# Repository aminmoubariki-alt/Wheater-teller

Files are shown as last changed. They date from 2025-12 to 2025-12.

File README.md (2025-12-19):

# IoT moubara

Repository of Amin Moubariki (500860959)
This is my first commit!
het gaat nu goed met git

## Week 1

Dinsdag 6 september.
Vandaag ben ik begonnen met de Git workshop, helaas heb ik deze niet helemaal afgemaakt, omdat ik ook nog mijn wemos ging solderen.
Morgen ga ik verder met het laten werken van Git, Het solderen is goed gelukt en het installeren van de arduino software ook.

Woensdag 7 september.
Vandag heb ik de tutorial afgemaakt en mijn Git pagina werkend gekregen. De eerst commits staan er succesvol om als ik naar mijn pagina ga op gitlab.

Doenderdag 8 September.
Tijdens de les van Joey heb ik al een beetje kunnen oefenen met 3D printing, Ik heb ervoor gekozen om een sleteulhanger te printen.
Het downloaden en bewerken van het design is goed gelukt en ik heb al beter begrepen hoe ik de 3D printer kan gebruiken. 

## Week 2

Maandag 12 september.
Ik heb mijn tempratuursensor succesvol geinstaleerd, Het laten werken van ervan lukt nog niet echt.
Dat is voor deze week mijn uitdaging.

Woensdag 14 september.
Vandaag heb ik mijn documentatie ook daadwerkelijk gecommit zodat het op mijn pagina op gitlab komt te staan.
Verder heb ik aan mijn weather station blueprint gewerkt en een scherm toegevoegd aan het breadboard met behulp van een backpack.
Ik heb het scherm aan de backpack gesoldeerd zodat ik het scherm makkelijker kan verwerken later in mijn project.

## Week 3

Maandag 19 september.
Het is vandaag een wat mindere dag qua progressie. Mijn git geeft steeds aan fatal code en het is mij niet gelukt om er zelf uit te komen,
Deze code kwam steeds wanneer ik iets probeerde te committen. Ik ben er vandaag niet uitgekomen en ga deze week daarom om hulp vragen.

Woensdag 21 september.
Het doel van vandaag was mijn git op orde krijgen zodat ik elke dag kan committen en pushen naar mijn pagina op gitlab.
Het is gelukt, een medestudent heeft alles op orde gekregen en mijn map via github geconnect met mijn pagina. 
Nu kan ik weer pushen en committen en blijven documenteren terwijl de docenten dat ook kunnen zien.

## Week 4

Maandag 26 september.
Ik heb vandaag feedback gevraagd voor Physical design van mijn wheaterstation. Ik heb Foto's gemaakt van mijn embedded device en deze toegevoegd aan het markdown bestand.
Aan mijn embedded device is een tempratuursensor aan verbonden en een lcd scherm met de wemos. Mijn scherm is nog blauw en speelt nog niks af en daar ga ik deze week mee aan de slag.
Het doel voor deze week is dus vooral ervoor zorgen dat mijn display op zijn minst de tempratuur kan afspelen.

Dinsdag 27 september.
Vandaag heb ik geprobeerd om wat meer te leren over PHP en om tekste af te spelen op mijn LCD scherm. Ik heb een hele rare error gekregen namelijk dat er geen poort geselecteerd is.
Dit is gek want ik heb aan het begin van dit project de CH340 driver succesvol geinstalleerd. Ik moet nu eerst dit probleem oplossen voordat ik echt verder kan helaas.
De code om iets af te spelen op mijn scherm klopt, er zaten geen fouten in en het zou helemaal moeten kloppen.
Het probleem is nu vooral dat de arduino app en mijn pc mijn embedded device niet kan herkennen en daar moet ik nu achteraan.

Woensdag 27 september.
Het maken van de poort gaat nog niet helemaal als gepland. Ik heb alles geprobeerd en ik zie dat het mij deze week heel veel tijd heeft gekost en mij heeft afgeremd.
Ik heb daarom besloten om te kijken naar mijn website met docker en daar is het ook gelijk fout gegaan, omdat WSL mist. Dus ik moet nu weer wat anders gaan doen.
Deze knelpunten hoop ik deze week te hebben verholpen anders ga ik vertraging oplopen en de deadline van de blueprint fase niet halen.

## Week 5

Maandag 3 Oktober.
Vandaag heb ik geprobeerd om aan mijn project te werken maar doordat ik ziek was heb ik weinig kunnen toevoegen, ik ben daarom ook niet lang op de campus gebleven.
Vandaar dat er daarom weinig is aangevuld en mijn problemen (port vooral) nog niet zijn opgelost. Ik hoop dat ik morgen een flinke slag kan maken.

Dinsdag 4 Oktober.
Het is eindelijkt gelukt om mijn poort werkend te krijgen, ik had blijkaar allemaal oplaadkabels getest in plaats van data-kabels zonder dat ik dat wist.
er was ook al een hoop gedoe met mijn website wat vandaag ook verholpen is door de map te verplaatsten. Gelukkig werkt alles nu zoals het hoort en moet er nu een slag worden gemaakt met mijn code.
De arduino code krijg ik maar niet werkend en de tijd begint echt te dringen. Ik hoop daat ik morgen dan ook mijn arduino code grotendeels af en werkend kan hebben.
Ik wil verder ook nog ervoor zorgen er nog 1 input sensor en 1 output part wordt toegevoegd zodat ik dat ook met mijn code kan invoegen.

Woensdag 5 Oktober.
Het gaat de verkeerde kant op met mijn blueprint, zojuist heb ik erachter gekomen dat er kortsluiting is op mijn embedded device waar ik nu een maand mee bezig ben.
Alles heb ik van mijn breadbord uit moeten halen en nu ben ik helemaal opnieuw begonnen met in elkaar zetten. De code werkt ook niet zoals verwacht.
Mijn Wemos verbind goed met mijn pc alleen als ik wat wil afspelen op het display komt er niks tevoorschijn. De Wemos is goed verbonden met het display.
Dit is wel een zware tik voor mij net nu ik dacht dat ik het wel begreep, ik moet nu bijna als het ware weer bij nul beginnen met nog een week te gaan.

## Week 6

Maandag 10 Oktober.
Deze maandag ben ik weer niet lekker uit bed gestapt, ik probeer morgen met wat paracetamol naar school te komen.

Dinsdag 11 Oktober.
Vandaag ben ik erachter gekomen dat mijn lcd scherm totaal niet functioneert er gaat alleen stroom naar het scherm toe thats it.
Na wat research geedaan te hebben ben ik op het arduino forum tegengekomen dat het wellicht met het soldeerwerk te maken heeft.
Ik heb vervolgens het scherm opnieuw gesoldeerd (nieuw scherm dit keer) en na wat zoeken en sleutelen doet mijn scherm het weer volledig.
Dit heeft mij enorm weerhouden van mijn vooruitgang en ik ben hier veel telaat achter gekomen. Het kan niet zo langer doorgaan op deze manier werken.
Volgende stap is om de tempratuur sensor af te spelen op mijn LCD scherm.

Woensdag 12 Oktober.
Vandaag heb ik mijn tweede performance review gehouden met mijn coach Mats. Het gaat niet goed met mijn vooruitgang en er moet snel iets veranderen.
Ik loop zwaar achter aangezien de blueprint fase deze week al af had moeten zijn. Momenteel heb ik een tempratuursensor en een LCD scherm derin zitten.
De tempratuur sensor is werken en er moet alleen nog code worden toegevoegd om deze af te spelen op mijn LCD scherm.
Er moet verder nog gewerkt worden aan de web applicatie en de database daarvan. Mijn plan is om dit over twee weken af te hebben met feedback om de puntjes op de I te zetten.

Herfstrecess.
Tijdens dit recess heb ik een flinke slag moeten maken met het werkend maken van mijn blueprint. Dat is aardig gelukt het embedded gedeelte is nu bijna af en werkt volledig.
Zo heb ik een tempratuursensor toegevoegd en worden de waarden die worden gemeeten op mijn display afgespeeld. Het heeft even geduurd maar alles werkt nu op het eerste gezicht en moet nog breed getest worden.
Ik heb een website die nog leeg is en een zeer beperkte database waar allen de tempratuur op wordt opgeslagen. Na het testen wil ik nog een knop, humiditysensor en een twee leds toevoegen aan mijn device.
Zoals het er voor nu uitziet ben ik goed opweg en moet ik vooral aan mijn documentatie, web app en database gaan werken voor dit project.

Maandag 24 Oktober.
Vandaag het ik mijn wheaterstation met de API verbonden zodat er ook vannuit daar informatie kan worden opgehaald en natuurlijk worden afgespeeld op het lcd scherm.
Het plan voor nu is om ervoor te zorgen dat zowel de tempratuur van buiten, met behulp van de API, als de binnentempratuur op het beeldscherm wordt afgespeeld.
Dit ga ik morgen proberen uitbreiden naar humidity van binnen door een DHT11 sensor toe te voegen aan mijn device.
Voordat ik een sensor ga toevoegen moeten de juiste waardes met de huidige tempratuursensoor goed worden afgespeeld.

Dinsdag 25 Oktober.
Het is mij gelukt om de DHT11 sensor toe te voegen zodat ik de lokaale humidity kan afspelen met de tempratuur.
Ook ben ik er achtergekomen dat deze DHT11 sensor de tempratuur accurater meet en, daarom heb ik besloten om mijn KY001 niet meer te gebruiken.
Nu ga ik ervoor zorgen dat de binnen en buiten humidity en tempratuur correct worden afgespeeld op mijn LCD scherm met behulp van de sensoren en de API.

Woensdag 26 Oktober.
Uit de performance review dat ik vandaag heb gehouden met mijn coach is gebleken dat ik flink vooruit ben gegaan, maar dat eer nog genoeg te doen is.
Daarom ga ik ook zo snel moegelijk beginnen met het vragen voor feedback voor de embedded kant, omdat ik daar veel aan gewerkt heb.
De kant waar nog best wat aan gedaan moet worden is de web app en de database daarvan. Ik hoop deze uiterlijk voor de volgende performance review af te hebben.
Voor de volgende performance review hoop ik ook het grootste gedeelte van de feedback te hebben ontvangen.

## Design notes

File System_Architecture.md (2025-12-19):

# System Architecture

## Introductie

In dit document beschrijf ik de systeemarchitectuur van mijn IoT-project. Het doel van deze architectuur is om in één overzicht te laten zien welke hardware- en softwarecomponenten worden gebruikt, hoe deze zijn gegroepeerd in subsystemen en via welke protocollen data door het systeem stroomt. Door deze structuur expliciet vast te leggen, wordt het systeem beter te begrijpen, eenvoudiger te onderhouden en makkelijker uit te breiden in een latere fase.

De oplossing bestaat uit een embedded device (WeMOS D1), een lokaal gehoste webomgeving (Docker op een Windows laptop), een database en meerdere externe systemen zoals het internet, een tunnelservice en een Git-repository.

---

## Legenda

- **[HW]** = Hardware component  
- **(SW)** = Software component  
- **[[DATA]]** = Data / opslag  
- **{EXT}** = Extern systeem  

Pijlen geven de **richting van de datastroom** aan.  
Elke pijl bevat:
- het gebruikte **protocol** (bijv. HTTP, I2C, MySQL)
- de **TCP/IP-poort** (indien van toepassing)

---

## System Architecture Diagram

```mermaid
flowchart TB

subgraph NET["SAD#15 {EXT} Internet / Intranet"]
  WEATHER_API["(SW) Externe Weather API\nHTTP :80\napi.iot.hva-robots.nl"]
  LHR_ADDR["(SW) Publiek tunnel-adres\n*.lhr.life"]
end

subgraph AP["SAD#13 {EXT} Network Access Point"]
  WIFI["[HW] WiFi Access Point (iotroam)"]
end

subgraph EMB["SAD#06 Embedded System"]
  WEMOS["[HW] WeMOS D1 (ESP8266)"]
  FW["(SW) C/C++ Firmware"]
  LIBS["(SW) Arduino Libraries\nESP8266WiFi, HTTPClient,\nArduinoJson, DHTesp"]
  DHT11["[HW] DHT11 Sensor"]
  LCD["[HW] LCD 16x2 + I2C Backpack"]

  WEMOS --> FW
  FW --> LIBS
  DHT11 -->|GPIO| WEMOS
  WEMOS -->|I2C| LCD
end

subgraph HOST["SAD#11 Host System"]
  OS["(SW) Windows OS"]

  subgraph DOCKER["SAD#10 Docker Host"]
    NETW["[HW] Docker Network (virtueel)"]

    subgraph WEB["SAD#07 Webserver"]
      NGINX["(SW) Nginx\nHTTP :80"]
      PHPFPM["(SW) PHP-FPM 8.1\nFastCGI :9000"]
    end

    subgraph FRONT["SAD#07A Frontend"]
      FE_FILES["(SW) HTML / CSS / JavaScript"]
      FE_PHP["(SW) Frontend PHP-bestanden"]
    end

    subgraph BACK["SAD#07B Backend"]
      API_PHP["(SW) API PHP-bestanden\n(database.php)"]
      BACK_LIBS["(SW) PHP libraries\n(mysqli)"]
    end

    subgraph DB["SAD#08 Database"]
      MARIADB["(SW) MariaDB\nTCP :3306"]
      DBINST["[[DATA]] Database instance"]
    end

    PMA["(SW) phpMyAdmin"]
    LHR["(SW) localhost-run service\nHTTP :8000"]

    NETW --- NGINX
    NETW --- PHPFPM
    NETW --- MARIADB
    NETW --- PMA
    NETW --- LHR

    NGINX -->|FastCGI :9000| PHPFPM
    PHPFPM --> FE_FILES
    PHPFPM --> FE_PHP
    PHPFPM --> API_PHP
    API_PHP -->|MySQL :3306| MARIADB
    MARIADB --> DBINST
    PMA -->|MySQL :3306| MARIADB
    NGINX -->|HTTP :80 /phpmyadmin| PMA
  end
end

subgraph CLIENT["SAD#12 {EXT} Mobiel apparaat"]
  PHONE["[HW] Smartphone"]
  OS_M["(SW) Android / iOS"]
  BROWSER["(SW) Webbrowser"]

  PHONE --> OS_M --> BROWSER
end

WEMOS -->|WiFi| WIFI
WIFI -->|HTTP :80 (GET)| WEATHER_API
WEMOS -->|HTTP :80 (GET sensor-data)| LHR_ADDR
LHR_ADDR -->|HTTP :80| NGINX
BROWSER -->|HTTP :80| NGINX

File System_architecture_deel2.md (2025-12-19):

### SAD#06 — Embedded system (subsystem)

**Doel**  
Meten en tonen van waarden en het doorsturen van meetgegevens via WiFi.

**Componenten**
- **[HW] WeMOS D1 (ESP8266)**  
  Microcontroller met ingebouwde WiFi-functionaliteit.
- **(SW) C/C++ firmware**  
  De hoofdapplicatie die draait op de WeMOS.
- **(SW) Arduino libraries**  
  Gebruikte libraries zijn onder andere:
  - `ESP8266WiFi`
  - `HTTPClient`
  - `ArduinoJson`
  - `DHTesp`
- **[HW] Sensoren**  
  - DHT11 sensor voor temperatuur- en luchtvochtigheidsmetingen.
- **[HW] LCD 16x2 + I2C backpack**  
  Display voor het tonen van meetwaarden.
- **[HW] Arduino UNO R3**  
  Niet gebruikt in dit project en daarom geen onderdeel van de werkende opstelling.

**Communicatie**
- **I2C** tussen de WeMOS en het LCD-scherm.
- **WiFi** voor communicatie met het netwerk en de webserver.

---

### SAD#07 — Webserver (subsystem)

**Doel**  
Ontvangen en afhandelen van HTTP-verzoeken en het uitvoeren van PHP-code.

**Componenten**
- **(SW) Nginx**  
  Webserver die luistert op **HTTP poort 80**.
- **(SW) PHP-FPM 8.1**  
  Verwerkt PHP-code en is gekoppeld aan Nginx via **FastCGI poort 9000** (intern).

**Bijzonderheden**
- phpMyAdmin is bereikbaar via de Nginx reverse proxy op:  
  `http://localhost/phpmyadmin/`

---

### SAD#07A — Frontend (subsystem)

**Doel**  
Het aanbieden van een gebruikersinterface in de webbrowser.

**Componenten**
- **(SW) HTML-bestanden**
- **(SW) CSS-bestanden**
- **(SW) JavaScript-bestanden**
- **(SW) Frontend PHP-bestanden**  
  PHP-bestanden die HTML-pagina’s renderen.
- **(SW) Frontend libraries**  
  Indien gebruikt; niet projectspecifiek vastgelegd.

**Communicatie**
- Webbrowser → Nginx via **HTTP poort 80**.

---

### SAD#07B — Backend (subsystem)

**Doel**  
Server-side verwerking van meetgegevens en communicatie met de database.

**Componenten**
- **(SW) API PHP-bestanden**  
  Onder andere `database.php`, dat meetgegevens ontvangt.
- **(SW) Backend libraries**  
  De `mysqli` extensie voor communicatie met MariaDB.

**Communicatie**
- **WeMOS → Nginx** via **HTTP poort 80** (GET-requests met queryparameters).
- **Backend → MariaDB** via **MySQL protocol poort 3306**.

**Toelichting**
De exacte `INSERT`-implementatie is niet opgenomen omdat de PHP-file met database-logica niet teruggevonden kon worden. Uit de WeMOS-code blijkt wel dat `database.php` wordt aangeroepen voor het opslaan van meetgegevens.

---

### SAD#08 — Database system (subsystem)

**Doel**  
Persistente opslag van meetgegevens.

**Componenten**
- **(SW) MariaDB**  
  Databaseserver die luistert op **TCP poort 3306**.
- **[[DATA]] Database**  
  Logische database (schema).
- **[[DATA]] Database instance**  
  Tabellen en records met meetdata.

**Beheertool**
- **(SW) phpMyAdmin**  
  Wordt gebruikt voor inspectie en beheer van de database.

---

### SAD#09 — Docker registry (external system)

**Doel**  
Aanbieden van Docker images die door het systeem worden gebruikt.

**Componenten**
- **{EXT} Docker registry**  
  Bijvoorbeeld Docker Hub.
- **[[DATA]] Docker images**  
  Onder andere:
  - `nginx:latest`
  - `mariadb:latest`
  - `phpmyadmin/phpmyadmin:latest`

---

### SAD#10 — Docker host (subsystem)

**Doel**  
Het draaien van containers en het faciliteren van onderlinge communicatie.

**Componenten**
- **[HW] Docker network (virtueel)**  
  Virtueel netwerk voor containercommunicatie.
- **[HW] Docker containers (virtueel)**  
  - nginx  
  - php-fpm  
  - mariadb  
  - phpMyAdmin  
  - localhost-run  

**Belangrijke poorten**
- Host → Nginx: **80:80**
- Host → MariaDB: **3306:3306** (lokaal, voornamelijk voor development)

---

### SAD#11 — Host System (subsystem)

**Doel**  
Fysieke machine waarop Docker draait.

**Componenten**
- **[HW] Windows laptop**
- **(SW) Windows OS**
- **(SW) Docker (native)**

---

### SAD#12 — Mobile Device (external system)

**Doel**  
Client voor het bekijken van de webinterface.

**Componenten**
- **{EXT} [HW] Smartphone**
- **{EXT} (SW) Android of iOS**
- **{EXT} (SW) Webbrowser**

---

### SAD#13 — Network Access Point (external system)

**Doel**  
Verzorgen van WiFi-connectiviteit voor het embedded device.

**Component**
- **{EXT} [HW] WiFi access point**  
  SSID: `iotroam`

---

### SAD#14 — Git repository (external system)

**Doel**  
Versiebeheer en opslag van de projectbroncode.

**Component**
- **{EXT} (SW) Git repository**  
  Bijvoorbeeld GitHub of GitLab.

---

### SAD#15 — Internet / Intranet (abstraction)

**Doel**  
Abstractie voor externe netwerkcommunicatie.

**Voorbeelden**
- WeMOS → externe weather API via **HTTP**.
- WeMOS → publiek tunnel-adres (`*.lhr.life`) richting het lokale systeem.

---

### SAD#16 — SSH-tunnel (subsystem)

**Status**  
Niet gebruikt.

Publieke toegang tot de lokale webomgeving verloopt via de `localhost-run` / `lhr.life` tunnelservice (HTTP). Er wordt geen SSH-tunnel toegepast.

---

### Conclusie

De systeemarchitectuur beschrijft de volledige keten van **sensor → embedded device → netwerk → webserver/backend → database**. Alle componenten zijn logisch gegroepeerd in subsystemen, hiërarchisch genest en gekoppeld via duidelijk gedefinieerde protocollen en poorten.

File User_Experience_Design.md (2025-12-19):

# User Experience Design

## Introductie

In deze opdracht wordt het User Experience Design (UXD) van het Weather Station IoT-project uitgewerkt aan de hand van de beschikbare knowledgebase en beoordelingsrubrics.  
Het doel van deze sectie is om te beschrijven hoe gebruiksvriendelijkheid, duidelijkheid en interactie met de gebruiker zijn meegenomen in het ontwerp van het systeem.  
De focus ligt op de interactie tussen de gebruiker en het systeem, zowel op het embedded device als op de webinterface.

---

## Context en Doelgroep

Het Weather Station is ontworpen voor gebruikers die op een snelle en eenvoudige manier inzicht willen krijgen in weerinformatie, zonder technische complexiteit.  
De doelgroep bestaat uit studenten en niet-technische gebruikers die basisgegevens zoals temperatuur en luchtvochtigheid intuïtief willen kunnen aflezen.

Het systeem is bedoeld voor gebruik in een gecontroleerde omgeving (campus of thuis), waarbij betrouwbaarheid en eenvoud belangrijker zijn dan uitgebreide configuratiemogelijkheden.

---

## Gebruikersdoelen

De belangrijkste doelen van de gebruiker bij het gebruik van het systeem zijn:
- Snel actuele temperatuur- en luchtvochtigheidswaarden kunnen bekijken.
- De weergegeven informatie begrijpen zonder technische voorkennis.
- Met minimale fysieke interactie het systeem kunnen bedienen.
- Duidelijke feedback ontvangen bij interactie met het systeem.

---

## User Interface Ontwerp

### Embedded Device Interface

Het embedded device maakt gebruik van een 16x2 LCD-display als primaire gebruikersinterface.  
Op het display wordt alleen de meest relevante informatie (temperatuur en luchtvochtigheid) getoond, zodat de gebruiker niet wordt overspoeld met informatie.

Ontwerpkeuzes:
- Beperkte hoeveelheid informatie per scherm om cognitieve belasting te verminderen.
- Hoog contrast (witte tekst op blauwe achtergrond) voor goede leesbaarheid.
- Vaste tekst gecombineerd met dynamische sensorwaarden.

Een fysieke drukknop wordt gebruikt voor interactie met het display, bijvoorbeeld om het scherm aan of uit te zetten.  
Dit houdt de bediening eenvoudig en verkleint de kans op foutieve invoer.

Daarnaast is een buzzer toegevoegd als sensorische output, zodat gebruikers ook auditieve feedback kunnen krijgen bij interactie.

---

## Interactieflow

1. Het device start op en maakt automatisch verbinding met het netwerk.
2. Sensorwaarden worden op de achtergrond uitgelezen.
3. De weerinformatie wordt weergegeven op het LCD-display.
4. De gebruiker kan via de drukknop met het display interacteren (bijvoorbeeld het scherm aan- of uitzetten).
5. Feedback wordt gegeven via visuele (LCD) en sensorische (buzzer) outputs.

Deze flow is bewust kort en voorspelbaar gehouden om gebruikersfouten te minimaliseren.

---

## Consistentie en Eenvoud

Consistentie wordt bereikt door:
- Altijd dezelfde layout op het LCD-display te gebruiken.
- Slechts één vorm van fysieke interactie aan te bieden (de drukknop).
- Duidelijke labels en eenheden te gebruiken (°C, %).

Het systeem vermijdt onnodige menu’s of instellingen en sluit daarmee aan bij de behoeften van de doelgroep.

---

## Toegankelijkheid

Bij het ontwerp is rekening gehouden met basisprincipes van toegankelijkheid:
- Grote en goed leesbare tekens op het LCD-display.
- Een minimaal aantal interactiestappen.
- Zowel visuele als auditieve feedback.

Hoewel het systeem geen uitgebreide toegankelijkheidsopties biedt, zorgen deze keuzes voor een bruikbare ervaring voor een brede groep gebruikers.

---

## Evaluatie op Basis van de Rubric

Op basis van de UXD-rubric kan worden geconcludeerd dat:
- Het ontwerp is gericht op de gebruiker en diens doelen.
- De interactie eenvoudig en intuïtief is.
- Visuele en sensorische feedback consistent wordt toegepast.
- Het systeem voldoet aan het verwachte niveau voor User Experience Design.

---

## Conclusie

Het User Experience Design van het Weather Station is gericht op eenvoud, duidelijkheid en gebruiksgemak.  
Door de interactie bewust beperkt te houden en duidelijke feedback te geven via visuele en sensorische middelen, biedt het systeem een intuïtieve gebruikerservaring voor de beoogde doelgroep.

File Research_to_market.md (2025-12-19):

# Research to Market  
## Business & Sustainability  
### IoT Wheaterstation  
**Auteur:** Amin Moubariki  

---

## Introduction / context  

Tijdens het ontwikkelen van mijn IoT Wheaterstation heb ik vooral gefocust op het technisch werkend krijgen van het systeem: sensoren uitlezen, data tonen en werken met een microcontroller. Het resultaat is een functionerend prototype dat geschikt is om te leren hoe embedded systemen en IoT-oplossingen zijn opgebouwd. Tegelijkertijd werd duidelijk dat dit prototype nog ver verwijderd is van een product dat daadwerkelijk verkocht zou kunnen worden.

Een concreet voorbeeld hiervan is het gebruik in het onderwijs. Wanneer een docent bijvoorbeeld twintig van deze weerstations zou willen inzetten in een practicum, ontstaat al snel een probleem. De huidige opbouw met breadboards en jumper wires is foutgevoelig, lastig te onderhouden en moeilijk te repareren. Als één sensor defect raakt, is het vaak eenvoudiger om het hele systeem te vervangen dan om het te herstellen. Dit is niet alleen kostbaar, maar ook niet duurzaam.

Dit onderzoek richt zich daarom op de vraag hoe dit prototype verbeterd kan worden zodat het dichter bij een marktwaardig product komt. De primaire doelgroep bestaat uit onderwijsinstellingen (MBO/HBO) en makers die een leerzaam, transparant en duurzaam IoT-product zoeken. Voor deze doelgroep is niet alleen functionaliteit belangrijk, maar ook levensduur, repareerbaarheid en inzicht in hoe het systeem is opgebouwd.

Voor de lezer is dit onderzoek relevant omdat het laat zien dat technische keuzes directe gevolgen hebben voor kosten, duurzaamheid en haalbaarheid. Een werkend prototype is niet automatisch een goed product, en juist in IoT-projecten wordt deze stap vaak onderschat.

---

## Research question  

**Hoe kan het IoT Wheaterstation worden doorontwikkeld tot een duurzaam en economisch haalbaar marktproduct, rekening houdend met productiekosten, verzending, belastingen, productverlies en structurele bedrijfskosten?**

### Deelvragen
1. Welke onderdelen van het huidige prototype zijn ongeschikt voor marktintroductie en waarom?  
2. Wat is een realistische kostprijs per geleverd product wanneer rekening wordt gehouden met verzending en 10% productverlies?  
3. Welke verkoopprijs is nodig om duurzaamheid, ondersteuning en doorontwikkeling mogelijk te maken?

---

## Research method  

Voor dit onderzoek is gekozen voor praktijkgerichte desk research. Deze methode past bij de onderzoeksvraag, omdat het doel niet is om gebruikersgedrag te meten, maar om de economische en logistieke haalbaarheid van het product te analyseren.

Allereerst is de bestaande Bill of Materials (BOM) geactualiseerd op basis van actuele prijzen bij Nederlandse leveranciers zoals TinyTronics en GAMMA. Deze BOM is bewust gebruikt als analyse-instrument en niet als eindoplossing.

Vervolgens zijn verzendkosten onderzocht aan de hand van officiële PostNL-tarieven voor nationale en internationale verzending. In alle berekeningen is expliciet rekening gehouden met het gegeven uit de opdracht dat 10% van de zendingen niet geleverd wordt. Deze aanname is consequent meegenomen in de effectieve kostprijs per geleverd product.

Daarnaast zijn relevante wetten en regels onderzocht, zoals btw-tarieven binnen Nederland en de EU, en Europese regelgeving rondom e-waste (WEEE/EPR). Ook zijn platformkosten (zoals Kickstarter-fees) meegenomen om een realistisch beeld te krijgen van de totale kostenstructuur.

---

## Results  

### Analyse van het prototype  

Uit de geactualiseerde BOM blijkt dat het huidige prototype ongeveer €32 tot €33 kost wanneer alle onderdelen los worden ingekocht. Deze prijs geeft een vertekend beeld, omdat arbeid, assemblage, kwaliteitscontrole, verpakking en verzending hierin niet zijn meegenomen. Daarnaast bevat het prototype onderdelen die ongeschikt zijn voor schaalbare productie, zoals breadboards, jumper wires en volledige weerstandensets.

Deze keuzes zijn logisch in een leercontext, maar problematisch bij herhaalbare productie. Ze verhogen de kans op fouten, maken reparatie lastig en leiden sneller tot vervanging in plaats van herstel.

### Van prototype naar marktversie  

Om deze problemen op te lossen is gekeken naar een conceptuele marktversie van het product. In deze versie wordt het breadboard vervangen door één PCB met alleen de noodzakelijke componenten. Sensoren blijven modulair zodat ze afzonderlijk vervangen kunnen worden. De behuizing wordt repareerbaar ontworpen, bijvoorbeeld met schroefverbindingen in plaats van lijm.

Deze ontwerpkeuzes verlagen de kans op defecten en retouren en sluiten beter aan bij duurzaamheidsprincipes (European Commission, 2022).

### Kostprijs, verkoopprijs en marge  

**Tabel 1 – Kostprijs en marge (excl. btw)**

| Component | Bedrag (€) |
|---|---|
| Productie (PCB, assemblage, behuizing, verpakking) | 25,50 |
| Opslag en kwaliteitscontrole | 1,50 |
| Productverlies (10%) | 2,80 |
| **Effectieve kostprijs per geleverd product** | **28,00** |
| **Verkoopprijs (direct-to-consumer)** | **79,00** |
| **Brutomarge per product** | **51,00** |

Deze tabel maakt duidelijk dat een verkoopprijs van €79 noodzakelijk is om ruimte te houden voor ondersteuning, retouren en verdere ontwikkeling.

---

## Verzending, btw en internationale verkoop  

Verzending binnen Nederland kost gemiddeld €6 tot €7 per pakket, terwijl verzending binnen Europa varieert tussen €9 en €13 (PostNL, 2025). Verzending buiten de EU is aanzienlijk duurder en brengt extra administratieve lasten met zich mee.

Binnen Nederland geldt een btw-tarief van 21% (Belastingdienst, 2024). Binnen de EU verschillen btw-tarieven per land. Buiten de EU worden import-btw en inklaringskosten meestal door de consument betaald.

---

## Implementation (koppeling met prototype)  

Foto’s van het huidige prototype zijn toegevoegd aan deze repository en tonen duidelijk waarom de huidige opbouw geschikt is als leerobject, maar niet als marktproduct. De zichtbare beperkingen van het prototype vormen de basis voor de voorgestelde verbeteringen.

Hoewel de marktversie in dit project nog niet fysiek is gerealiseerd, zijn de verbeteringen concreet uitgewerkt in ontwerpkeuzes, schema’s en kostenberekeningen. De implementatie is daarmee conceptueel afgerond en direct toepasbaar in een volgende ontwikkelfase.

---

## Conclusion  

Het IoT Wheaterstation kan alleen marktwaardig en duurzaam worden wanneer technische en zakelijke keuzes samen worden bekeken. Door over te stappen van een breadboard-opzet naar een PCB-gebaseerde, modulaire marktversie worden fouten, retouren en e-waste verminderd. Tegelijkertijd ontstaat ruimte voor een gezonde marge die nodig is om het product te ondersteunen en verder te ontwikkelen.

Duurzaamheid blijkt in dit onderzoek geen losstaand thema, maar een voorwaarde voor economische haalbaarheid.

---

## Recommendations  

Aanbevolen wordt om het prototype door te ontwikkelen naar een PCB-gebaseerde marktversie met modulaire sensoren en een repareerbare behuizing. Verzendkosten en belastingen moeten transparant worden gecommuniceerd en apart worden geprijsd.

Voor toekomstig onderzoek kan worden onderzocht hoe kostprijs en duurzaamheid veranderen bij grotere productieseries, bijvoorbeeld bij aantallen van 5.000 stuks of meer.

---

## Begrippenlijst  

**Bill of Materials (BOM)**  
Overzicht van alle onderdelen die nodig zijn om een product te bouwen, inclusief aantallen en kosten.

**Breadboard**  
Testbord voor elektronische prototypes zonder solderen; ongeschikt voor marktproducten.

**Brutomarge**  
Verschil tussen verkoopprijs en kostprijs van een product.

**COGS (Cost of Goods Sold)**  
Directe kosten om één product te maken en te leveren.

**Desk research**  
Onderzoeksmethode gebaseerd op bestaande bronnen zoals documentatie en rapporten.

**ESP8266**  
Microcontroller met ingebouwde wifi-functionaliteit, gebruikt in dit project via de Wemos D1 mini.

**IoT (Internet of Things)**  
Netwerk van fysieke apparaten die data verzamelen en uitwisselen via het internet.

**Modulair ontwerp**  
Ontwerp waarbij onderdelen afzonderlijk vervangen kunnen worden.

**PCB (Printed Circuit Board)**  
Printplaat waarop elektronische componenten permanent zijn gemonteerd.

**WEEE / EPR**  
Europese regelgeving voor inzameling en verwerking van elektronisch afval.

---

## References  

Baldé, C. P., Forti, V., Gray, V., Kuehr, R., & Stegmann, P. (2020). *The global e-waste monitor 2020*. United Nations University.  
https://www.globalewaste.org  

Belastingdienst. (2024). *Btw-tarieven*.  
https://www.belastingdienst.nl  

European Commission. (2022). *Sustainable products and circular economy*.  
https://environment.ec.europa.eu  

Gartner. (2023). *Why IoT projects fail to scale*.  
https://www.gartner.com  

Kickstarter. (n.d.). *Fees and pricing*.  
https://www.kickstarter.com/help/fees  

PostNL. (2025). *Tarieven pakketten Nederland en buitenland*.  
https://www.postnl.nl  

Your Europe – Business. (2024). *Waste electrical and electronic equipment (WEEE)*.  
https://europa.eu/youreurope/business

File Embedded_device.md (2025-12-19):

# Embedded Device

## Introduction

In this assignment the embedded device of the Weather Station project is evaluated against the defined system requirements.  
The embedded device is built using a WeMOS D1 Mini (ESP8266) in combination with multiple sensors and actuators.  
All verification is based on the current implementation available in the project repository.

---

## System Requirements

| Requirement ID# | Requirement | MoSCoW | Compliant |
|---|---|---|---|
| EMBRQ#01 | The embedded device acts as a client and sends measured sensor data to the application backend over http or https. | MUST | NO |
| EMBRQ#02 | The embedded device also acts as a server and receives status messages from the application backend over http or https. | MUST | NO |
| EMBRQ#03 | The embedded device contains at least two types of input sensors. | MUST | YES |
| EMBRQ#04 | The embedded device contains at least two types of visual and/or sensory outputs. | MUST | YES |
| EMBRQ#05 | The embedded device uses the WifiManager for configuration of SSID and password (PWD) for connecting to the network. | MUST | NO |

---

## EMBRQ#01 — Embedded device als client (sensor data versturen)

Het embedded device maakt gebruik van WiFi- en HTTP-communicatie via de `ESP8266WiFi` en `ESP8266HTTPClient` libraries.  
In de huidige implementatie wordt uitsluitend een HTTP **GET request** uitgevoerd naar een externe weather API (`api.iot.hva-robots.nl`) om weerdata op te halen.

Het embedded device verstuurt **geen gemeten sensordata** (zoals temperatuur of luchtvochtigheid van de DHT11) naar een eigen application backend via HTTP POST of PUT.

Omdat er geen gemeten sensordata van het device naar een backend wordt verzonden, is deze requirement **niet behaald**.

### Code bewijs

```cpp
WiFiClient client;
HTTPClient httpClient;

httpClient.begin(client, "http://api.iot.hva-robots.nl/weather/Amsterdam/compact");
int httpCode = httpClient.GET();
EMBRQ#02 — Embedded device als server (status ontvangen)
De huidige software start geen HTTP-server op het embedded device.
Er wordt geen WiFiServer of ESP8266WebServer geïnitialiseerd en er zijn geen endpoints beschikbaar waarmee een backend status- of control-berichten kan sturen naar het device.

Hierdoor kan het embedded device geen commando’s ontvangen, zoals het aan- of uitzetten van outputs via HTTP.

Omdat het device uitsluitend als client functioneert en niet als server, is deze requirement niet behaald.

Code bewijs
cpp
Copy code
#include <ESP8266HTTPClient.h>
#include <WiFiClient.h>
// Geen WiFiServer of ESP8266WebServer implementatie aanwezig
EMBRQ#03 — Minimaal twee typen input sensoren
Deze requirement is behaald.

Het embedded device bevat de volgende typen input:

DHT11 temperatuur- en luchtvochtigheidssensor (digitale sensor)

Drukknop als digitale input met interrupt

Code bewijs
cpp
Copy code
dht.setup(D5, DHTesp::DHT11);

int pinButton = D6;
pinMode(pinButton, INPUT);
attachInterrupt(digitalPinToInterrupt(pinButton), buttonPressed, RISING);
EMBRQ#04 — Minimaal twee typen output (visueel en/of sensorisch)
Deze requirement is behaald.

Het embedded device bevat de volgende output-typen:

LCD-display (16x2 met I2C) als visuele output

Buzzer als sensorische output

Het LCD-display wordt actief aangestuurd om data weer te geven.

Code bewijs (LCD)
cpp
Copy code
LiquidCrystal_I2C lcd(0x27, 16, 2);

lcd.begin();
lcd.backlight();
lcd.print(temp);
Hoewel de buzzer in de huidige code nog niet actief wordt aangestuurd, is deze wel onderdeel van de hardware-opstelling. Daarmee zijn twee verschillende output-typen aanwezig.

EMBRQ#05 — WiFi configuratie met WifiManager
Deze requirement is niet behaald.

Het embedded device maakt verbinding met het netwerk via hardcoded SSID- en wachtwoordgegevens.
De WifiManager library wordt niet gebruikt voor netwerkconfiguratie.

Hoewel deze keuze is gemaakt omdat het om een conceptmodel gaat dat uitsluitend op de campus wordt gebruikt, vereist de opdracht expliciet het gebruik van WifiManager.

Code bewijs
cpp
Copy code
#define ssid "iotroam"
#define password "ItjVWWl2mz"

WiFi.begin(ssid, password);
while (WiFi.status() != WL_CONNECTED) {
  delay(1000);
}
Wiring Diagram & BOM
Wiring Diagram
Een wiring diagram is een visuele weergave van hoe alle elektronische componenten (zoals de WeMOS, sensoren en actuatoren) fysiek met elkaar verbonden zijn op een breadboard.
Het doel van het wiring diagram is om het prototype reproduceerbaar te maken voor derden.

Het wiring diagram voor dit project is ontworpen met een dedicated electronics design tool en toont alle gebruikte componenten, voedingslijnen en signaalverbindingen.

(Het wiring diagram is beschikbaar via de IoT-portfolio website.)

Bill of Materials
Een Bill of Materials (BOM) is een overzicht van alle onderdelen die nodig zijn om het prototype te bouwen.
De BOM bevat partnummers, fabrikanten, aantallen en kosten zodat het project reproduceerbaar is.

Part number Manufacturer      Description Quantity    Price (incl. VAT) Subtotal (incl. VAT)    Example url
WMD1MINIV4  Lolin Wemos D1 Mini V4 (ESP8266, CH340)   1     €7,00 €7,00 https://www.tinytronics.nl
DHT11 TinyTronics DHT11 temperature & humidity sensor 1     €2,50 €2,50 https://www.tinytronics.nl
162LCDI2C   TinyTronics LCD display 16x2 with I2C backpack  1     €7,00 €7,00 https://www.tinytronics.nl
BBTACT      TinyTronics Breadboard push button  1     €0,15 €0,15 https://www.tinytronics.nl
BB830P      TinyTronics Breadboard 830 points   1     €3,00 €3,00 https://www.tinytronics.nl
DUPOMM100   TinyTronics Jumper wires male–male  1     €3,50 €3,50 https://www.tinytronics.nl

Program Code
Om sensoren uit te lezen en data te verwerken is het embedded device geprogrammeerd in C++ met behulp van de Arduino IDE.
De broncode volgt de gangbare Arduino-conventies en is beschikbaar in een publieke repository.

Repository
De volledige implementatie van het embedded device, inclusief alle broncode, is beschikbaar via:

https://github.com/aminmoubariki-alt/Wheater-teller

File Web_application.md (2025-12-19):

# Web Application – Wheater Station IoT

**Project:** Wheater Station
**Repository:** https://github.com/aminmoubariki-alt/Wheater-teller

---

## 1. Introductie

Dit document beschrijft de huidige status van de webapplicatie binnen het Wheater Station IoT-project.
De webapplicatie is bedoeld als centrale toegang tot sensordata die wordt verzameld door een embedded device (WeMOS D1).

Op dit moment ligt de focus van het project op het embedded device en de systeemarchitectuur. De webapplicatie bevindt zich nog in een vroege fase en bestaat voornamelijk uit **ontwerpkeuzes en voorbereidende documentatie**. Verdere implementatie (front-end, REST API en database) volgt in een latere iteratie.

---

## 2. Rol van de Web Application binnen het systeem

Binnen de totale systeemarchitectuur vervult de webapplicatie de volgende rollen:

- Ontvangen van sensordata via een API
- Opslaan van data in een database
- Beschikbaar stellen van data aan een front-end voor visualisatie

De webapplicatie fungeert als **enige toegangspunt tot de data**. Het embedded device communiceert niet rechtstreeks met de database.

---

## 3. Architectuurkeuzes (huidige stand)

### 3.1 Gelaagde opzet
De webapplicatie is conceptueel opgebouwd uit drie lagen:

1. **Back-end (REST API)**
Verantwoordelijk voor validatie, verwerking en opslag van data.

2. **Database**
Persistente opslag van sensormetingen met tijdstempels.

3. **Front-end (SPA)**
Visualisatie van actuele en historische meetwaarden.

Deze scheiding zorgt voor duidelijke verantwoordelijkheden en maakt het systeem uitbreidbaar.

### 3.2 Communicatie
- Embedded device → API: HTTP (JSON)
- Front-end → API: HTTP (JSON)
- API → Database: SQL

---

## 4. Technische documentatie

### 4.1 Gebruikte technologieën (voorlopig)

De volgende technologieën zijn gekozen of voorbereid:

- **HTTP + JSON**
Voor eenvoudige en platformonafhankelijke communicatie.
- **REST-architectuur**
Duidelijke endpoints, schaalbaar en goed testbaar.
- **Relationele database (MySQL)**
Geschikt voor gestructureerde tijdsgebonden data en eenvoudig te modelleren in MySQL Workbench.

Concrete implementaties van back-end en front-end zijn op dit moment nog niet aanwezig in de repository.

### 4.2 Ontwerpkeuzes

- Sensorwaarden worden altijd opgeslagen met een timestamp om historische analyse mogelijk te maken.
- De database wordt zo ontworpen dat nieuwe sensortypes toegevoegd kunnen worden zonder het schema aan te passen.
- De API wordt het enige toegangspunt tot de data (geen directe database-toegang).

### 4.3 Bekende beperkingen

- Er is nog geen geïmplementeerde REST API.
- Er is nog geen front-end applicatie beschikbaar.
- Er is nog geen database-schema of ERD toegevoegd.

Deze onderdelen vallen buiten de huidige scope en worden later uitgewerkt.

---

## 5. API Reference (conceptueel)

De API is nog niet geïmplementeerd. Onderstaande beschrijving geeft het **bedoelde ontwerp** weer.

### POST `/measurements`
Ontvangt sensordata van het embedded device.

**Voorbeeld payload:**
```json
{
"device_id": "wemos-d1-01",
"timestamp": "2025-12-19T21:30:00Z",
"values": [
{ "type": "temperature", "value": 21.4 },
{ "type": "humidity", "value": 48 }
]
}

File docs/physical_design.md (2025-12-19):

# Physical design
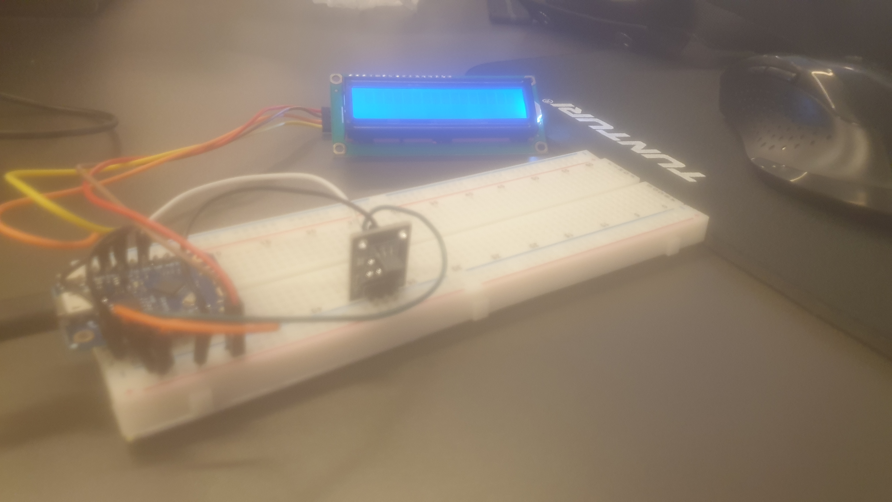
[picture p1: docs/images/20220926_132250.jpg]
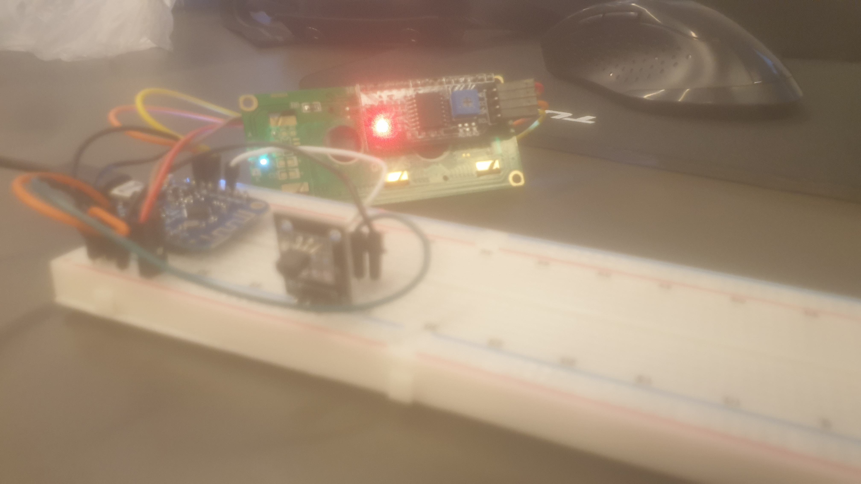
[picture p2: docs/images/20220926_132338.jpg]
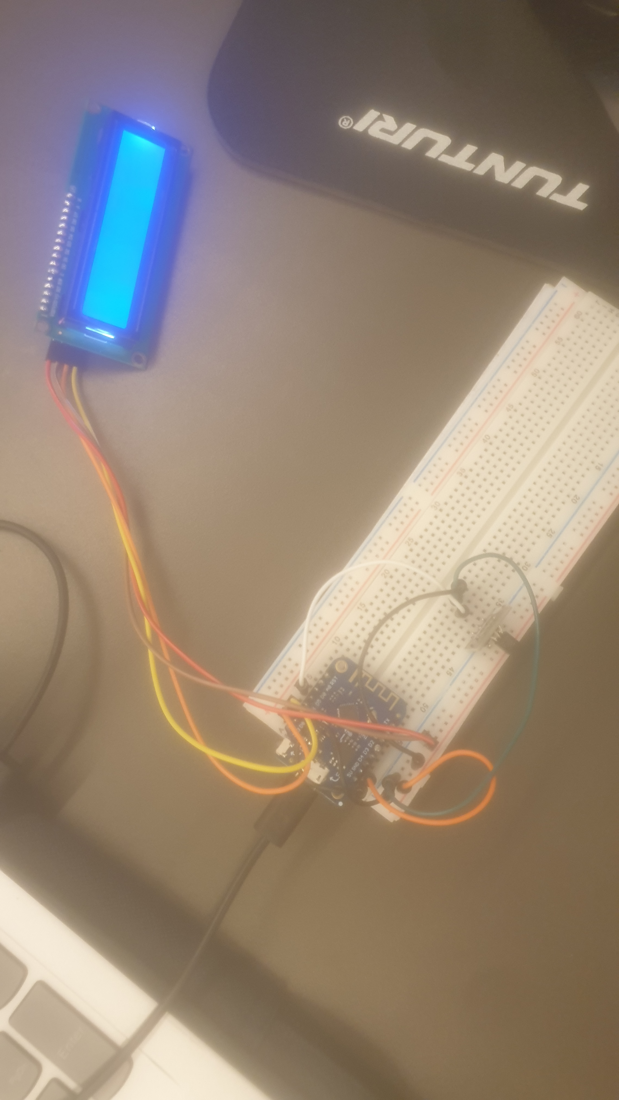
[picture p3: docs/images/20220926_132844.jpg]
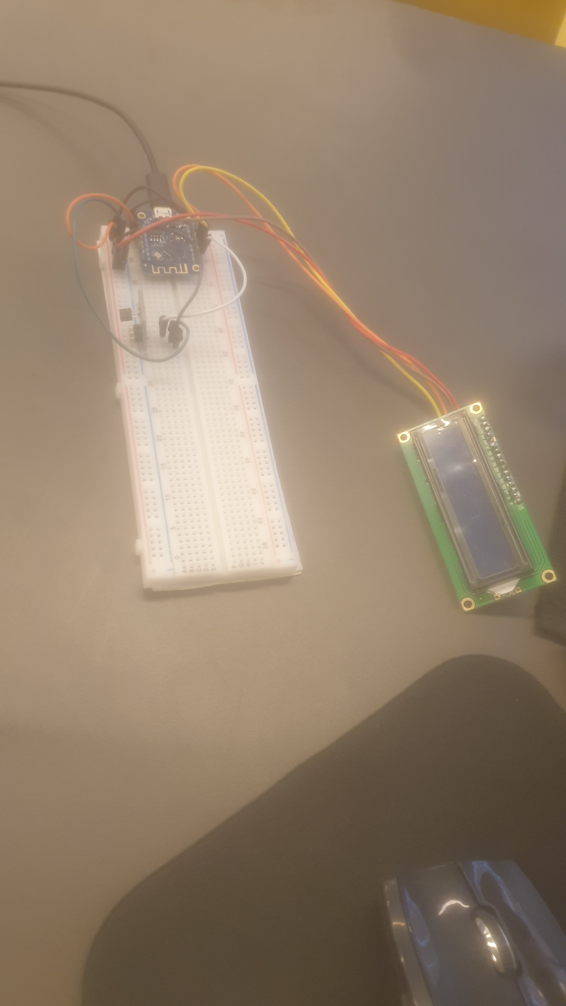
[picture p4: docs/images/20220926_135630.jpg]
   
## Concept

De blueprint wheaterstation is bedoeld voor voor gebruikers tussen de 18 en 40 jaar die veel buiten sprten en dit station gaan gebruiken voor de realtime tempratuur buiten. Ook is het de bedoelling dat deze gebruikers naar de vochtigheidsgraad kunnen kijken om zo te bepalen welke kleding ze gaan dragen voor het sporten buiten.

## Digital manufacturing materials and methods

## Design

Het design moet simpel zijn en vooral praktisch zijn voor outdoor use. het enige wat de gebruiker zou moeten zien is het scherm. De behuizing moet ervoor zorgen dat het product makkelijk te verplaatsen wordt en om de hardware te verbergen/beschermen.
## Prototype

Het prototype is goed op weg naar het gewenste resultaat, maar nog lang niet af, er zit een inputsensor (tempratuur) In en er zit output (Beeldscherm) aan gekoppeld. Ik heb zeker nog hulp nodig voor het eindproduct. Ik ben er nog niet helemaal uit wat de tweede outputsensor wordt en hoe ik dat gaat koppelen. Het einddoel is dat het product mobiel wordt en over in en om het huis te gebruiken is voor de gewenste output van de user.

## Create

## Conclusion

## Failures

!!! Failure
    Het beeldscherm is alleen blauw en laat geen tempratuur zien nog. Ik mis nog de juiste code voor de meting van de tempratuur zodat ik de tempratuur op het scherm kan afbeelden. 

!!! Failure
    Failure 2

!!! Failure
    Failure 3

!!! Failure
    Failure 4

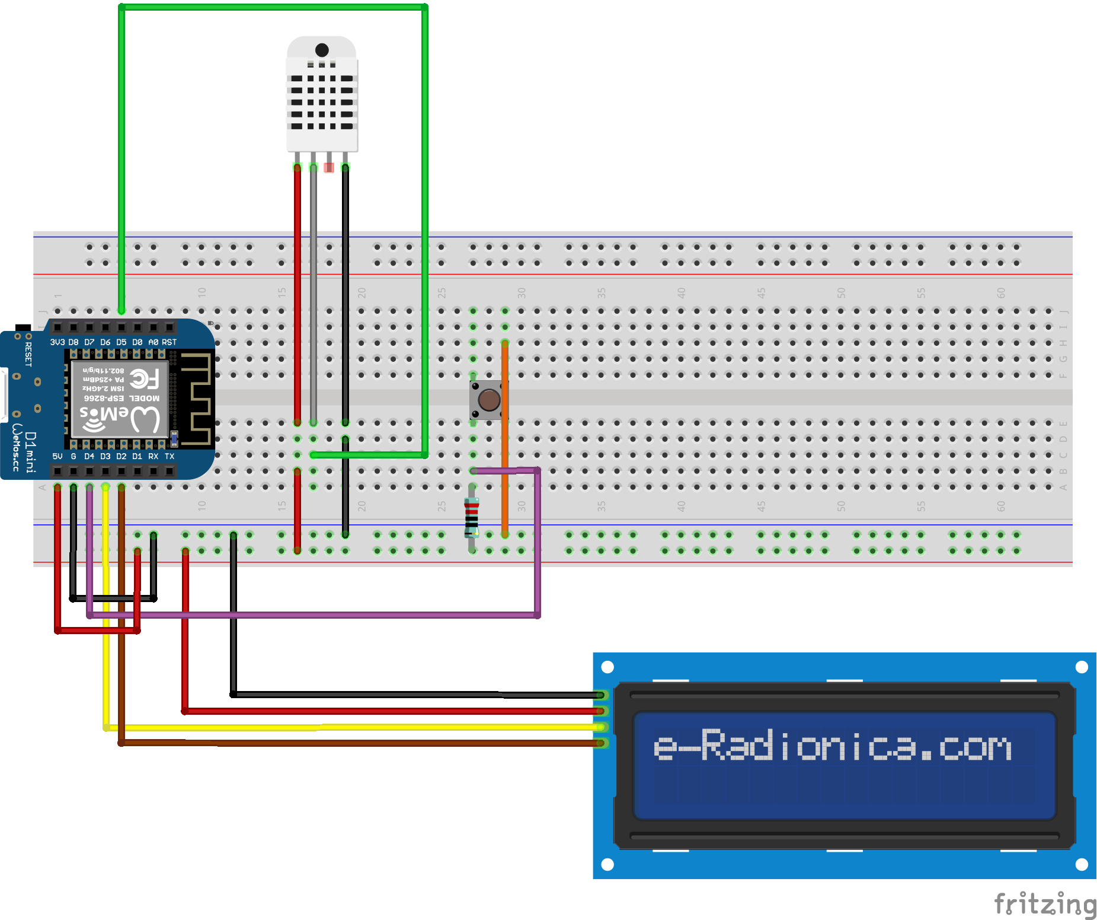
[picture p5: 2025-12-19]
docs/images/fritzing.png.png

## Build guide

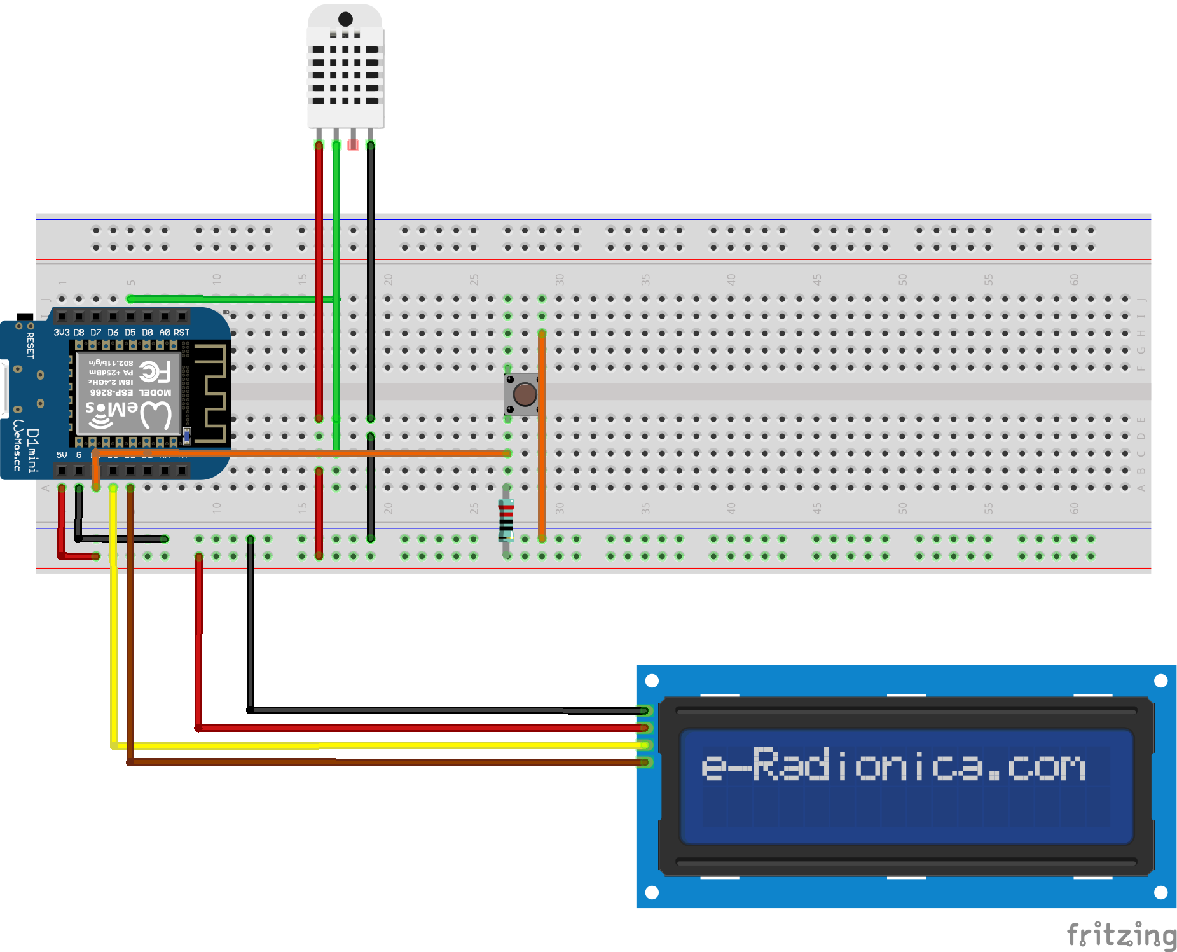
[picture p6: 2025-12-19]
Wiring Diagram Wheater station Amin Moubariki_bb.png

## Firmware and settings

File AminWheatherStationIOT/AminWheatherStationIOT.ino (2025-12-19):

#include "DHTesp.h"
DHTesp dht;
#include <LiquidCrystal_I2C.h>
LiquidCrystal_I2C lcd(0x27, 16, 2);

#define WEATHER_HOST "api.iot.hva-robots.nl"
#define LOCAL_HOST "SERVER HTTP"
#include <Arduino.h>
#include <ArduinoJson.h>

#include <ESP8266WiFi.h>
#include <ESP8266HTTPClient.h>
#include <WiFiClient.h>

#define ssid  "iotroam"
#define password "ItjVWWl2mz"

const apiUrl = "http://e12ab93365a8e7.lhr.life/"

void setup() {
  lcd.begin();
  dht.setup(D5, DHTesp::DHT11);

  Serial.begin(9600);
  WiFi.begin(ssid, password);

  // Keep in while-loop while the device is not connected to your accesspoint.
  while (WiFi.status() != WL_CONNECTED) {
    delay(1000); // Waiting on connection...
  }
}

void loop() {
  WiFiClient client;
  HTTPClient httpClient;

  httpClient.begin(client, "http://api.iot.hva-robots.nl/weather/Amsterdam/compact");
  int httpCode = httpClient.GET();

  if (httpCode == HTTP_CODE_OK) { // HTTP_CODE_OK == 200
    String payload = httpClient.getString();
    Serial.println(payload);


    StaticJsonDocument<1024> doc;

    DeserializationError error = deserializeJson(doc, payload);

    if (error) {
      Serial.print(F("deserializeJson() failed: "));
      Serial.println(error.f_str());
      return;
    }

    if (!error) {
      bool success = doc["success"]; // true

      JsonObject data = doc["data"];
      Serial.println("The data has been recieved");
      Serial.println(success);
      showDataOnLCD(data);

    }  else {
      Serial.print(F("deserializeJson() failed: "));
      Serial.println(error.f_str());
      return;
    }

  } else {
    Serial.println("Unable to connect :(");
  }

  delay(1000);
}
void showDataOnLCD(JsonObject data) {

  const char* data_FeelsLikeC = data["FeelsLikeC"]; // "19"
  const char* data_FeelsLikeF = data["FeelsLikeF"]; // "66"
  const char* data_cloudcover = data["cloudcover"]; // "25"
  const String data_humidity = data["humidity"]; // "64"
  const char* data_localObsDateTime = data["localObsDateTime"]; // "2022-07-04 10:33 AM"
  const char* data_observation_time = data["observation_time"]; // "08:33 AM"
  const char* data_precipInches = data["precipInches"]; // "0.0"
  const char* data_precipMM = data["precipMM"]; // "0.0"
  const char* data_pressure = data["pressure"]; // "1020"
  const char* data_pressureInches = data["pressureInches"]; // "30"
  const String data_temp_C = data["temp_C"]; // "19"
  const char* data_temp_F = data["temp_F"]; // "66"
  const char* data_uvIndex = data["uvIndex"]; // "4"
  const char* data_visibility = data["visibility"]; // "10"
  const char* data_visibilityMiles = data["visibilityMiles"]; // "6"
  const char* data_weatherCode = data["weatherCode"]; // "116"
  const char* data_weatherDesc_0_value = data["weatherDesc"][0]["value"]; // "Partly cloudy"
  const char* data_weatherIconUrl_0_value = data["weatherIconUrl"][0]["value"]; // nullptr

  const char* data_winddir16Point = data["winddir16Point"]; // "WSW"
  const char* data_winddirDegree = data["winddirDegree"]; // "250"
  const char* data_windspeedKmph = data["windspeedKmph"]; // "17"
  const char* data_windspeedMiles = data["windspeedMiles"]; // "11"


  // read the input on analog pin D5:
  float h = dht.getHumidity();
  float t = dht.getTemperature();
  String tempin = "IN:" + String(t);
  String humditiyout = " humid:" + data_humidity;
  String tempout = "OUT:" + data_temp_C;
  String humditiyin = "IN:" + String(h);
  lcd.setCursor(0, 0); // Sets the location at which subsequent text written to the LCD will be displayed
  lcd.print(tempin);
  lcd.print(humditiyin);
  lcd.setCursor(0, 1);
  lcd.print(tempout);
  lcd.print((char)223);
  lcd.print(humditiyout);
  //api calls.
  httpClient.begin(client, apiUrl . "database.php?type=out&humidity=" . data_humidity . "&celcius=" . data_temp_C);
  httpClient.GET();
  httpClient.begin(client, apiUrl . "database.php?type=in&humidity=" . String(h) . "&celcius=" . String(t));
  int httpCode = httpClient.GET();
  
  delay(5000);
  lcd.clear(); // Clears the LCD screen
}

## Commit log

2025-12-19 Updated project
    [Wiring Diagram Wheater station Amin Moubariki.fzz, fritzing.fzz, wiring_diagram_updated.fzz]
2025-12-19 Create ReasearchToMarket.md
    Het onderzoek is van de enen naar de andere bestandmap gekopieerd en opnieuw gemaakt en geactualiseerd anno dec 2025. Bestand is op nieuw gemaakt en gevuld met de inhoud
2025-12-19 Alle laatste opdrachten
    Dit zijn de opdrachten klaar om de link te delen.
